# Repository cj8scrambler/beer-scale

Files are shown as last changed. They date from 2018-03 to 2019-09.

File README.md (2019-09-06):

# Keg Scale
This is a project to monitor the amount of beer left in my keggerator by weighing them and providing a web interface to view the data.

### Architecture
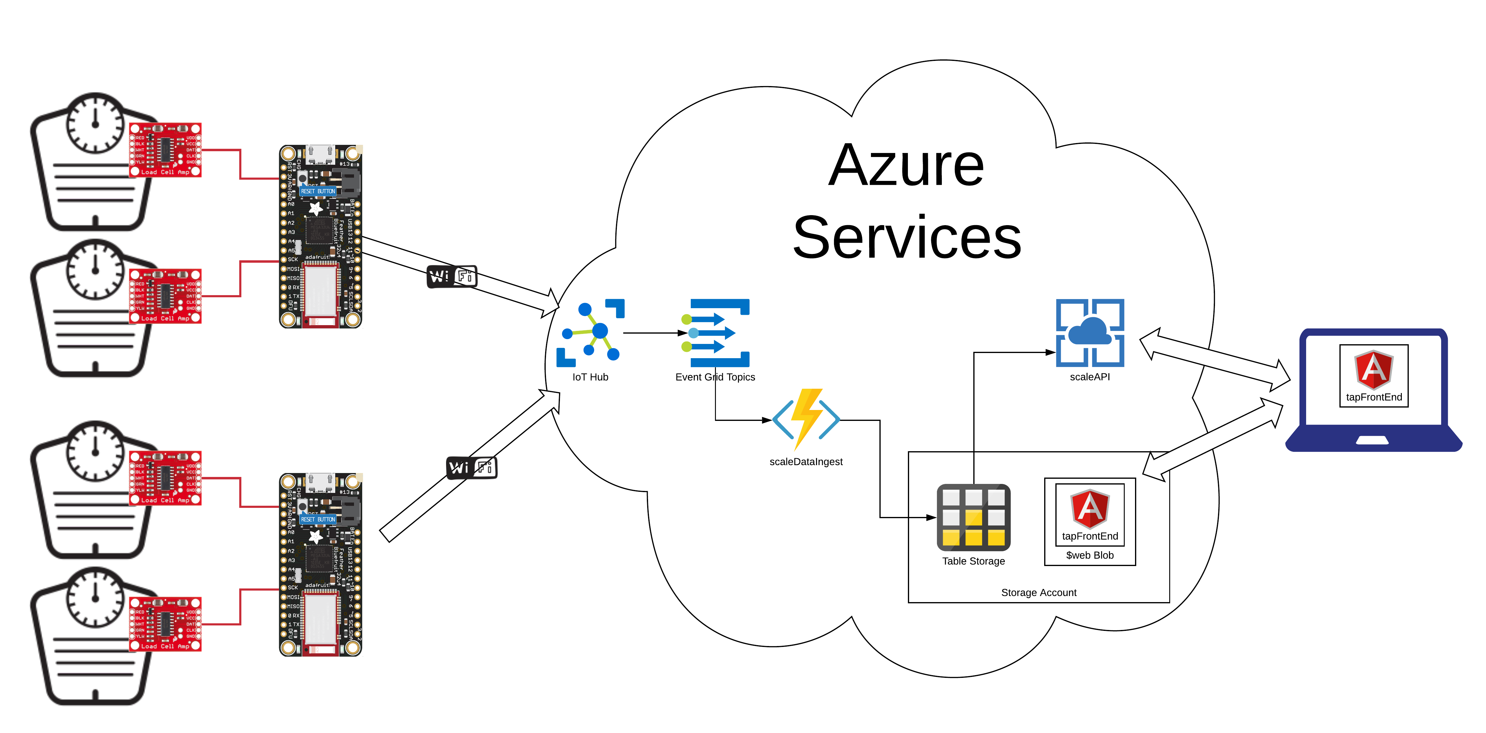
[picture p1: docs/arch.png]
arch


##### Scales
Custom scales were created which fit in the keggerator.  In my case they are 9" x 9.75".  The scales are made from a 1/2" thick sheet of HDPP plastic [cutting boards](https://www.amazon.com/gp/product/B01LXE0MBM/ref=oh_aui_search_detailpage?ie=UTF8&psc=1).  [50kg load cells](https://www.amazon.com/gp/product/B071ZYYJHJ/ref=oh_aui_search_detailpage?ie=UTF8&psc=1) are placed in each corner.  The load cells are held in place using a custom [3D printed clip](hw/).

##### Scale Wiring
Sparkfun has a great [tutorial](https://learn.sparkfun.com/tutorials/load-cell-amplifier-hx711-breakout-hookup-guide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) on wiring and using load cells.  I used their [Load Cell Combinator](https://www.sparkfun.com/products/13878) and [Qwiic Scale - NAU7802 board](https://www.sparkfun.com/products/15242) to wire up the scales for prototyping.  Eventually I will use a custom PCB for the scales' interface.

##### Reading Data
Currently data is read and sent to the cloud by a $10 [ESP8266 Huzzah](https://www.adafruit.com/product/2471).

##### Backend
I've included a [shell script](azure/provision.sh) which can be used to automaticlly provision all of the backend services needed on Azure from a Mac or Linux (possibly Windows too if there's a bash shell available).

##### Sending Data
The [Azure IOT SDK](https://github.com/Azure/azure-iot-sdk-c) is used to send data directly from the Arduino to the Azure backend.  Data is stored in Azure Table service which is the cheapest solution I could find.

##### Accessing Data
An Angular frontend app presents the data to the user.

### Organization
Each Arduino can handle up to 8 scales (using 4 NAU7802 devices).  Multiple Arduinos can be used and presented under a single web interface.

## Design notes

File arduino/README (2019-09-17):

Arduino IDE Setup:

  File->Preferences->Additional Boards Manager URLs: 
  *  https://arduino.esp8266.com/stable/package_esp8266com_index.json
  *  Be sure to install v2.4.2 to avoid issue: https://github.com/esp8266/Arduino/issues/5787

  Install Libraries:
  *  AzureIoTHub
  *  AzureIoTUtility
  *  AzureIoTProtocol_MQTT
  *  ArduinoJson
  *  SparkFun Qwiic Scale NAU7802 Arduino Library
     Be sure to install v1.0.3 or later to get my non-blocking calibration changes

-------------------------------------------------------------

Or build / upload directly from the command line:

  Install arduino-cli:
  *  curl -fsSL https://raw.githubusercontent.com/arduino/arduino-cli/master/install.sh | BINDIR=~/bin sh

  Configure arduino-cli:
  *  arduino-cli config init
  *  edit ~/.arduino15/arduino-cli.yaml and replace the board_manager line with:
     board_manager:
       additional_urls:
         - http://arduino.esp8266.com/stable/package_esp8266com_index.json
  *  arduino-cli core update-index

  Install dependencies:
  *  arduino-cli core install esp8266:esp8266@2.4.2
  *  arduino-cli lib install AzureIoTHub
  *  arduino-cli lib install AzureIoTUtility
  *  arduino-cli lib install AzureIoTProtocol_MQTT
  *  arduino-cli lib install ArduinoJson
  *  arduino-cli lib install "SparkFun Qwiic Scale NAU7802 Arduino Library"

  Build
  *  make 

  Upload 
  *  make upload        # set serial port path in Makefile

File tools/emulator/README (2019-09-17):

Python script to generate some dummy data emulating a scale
device.  If you don't have the arduino hardware working,
this can be used to fill the pipeline with some data.

Be sure to update the CONNECTION_STRING constant inside the
scale.py script!  The value to put here is printed by the
provision.sh script as "Node# Connection String" (where #
is any one of the multiple nodes available)

Script depends on the Azure IOT client python SDK which is
hard to install.  This is how I got it working:

# May need to add swap disk if < 2GB RAM avaialble
  sudo dd if=/dev/zero of=swapfile bs=1M count=3000
  sudo mkswap swapfile
  sudo swapon swapfile

# Pull Azure Python IOT SDK
git clone --recursive https://github.com/Azure/azure-iot-sdk-python.git
cd azure-iot-sdk-python/build_all/linux

# Build/Install for python 2
./setup.sh
./build.sh
cp ../../c/cmake/iotsdk_linux/python/src/iothub_client.so release_device_client/iothub_client/
cd release_device_client/
sudo python setup.py install
sudo cp -r iothub_client/ /usr/local/lib/python2.7/dist-packages/

# Clean up
cd -
git clean -xdf

# Build/Install for python 3
./setup.sh --python-version 3.6
./build.sh --build-python 3.6
cp ../../c/cmake/iotsdk_linux/python/src/iothub_client.so release_device_client/iothub_client/
cd release_device_client/
sudo python3 setup.py install
sudo cp -r iothub_client/ /usr/local/lib/python3.6/dist-packages/

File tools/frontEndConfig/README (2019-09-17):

Command line utility to configure the configuration database which the
frontend web app uses.

Be sure to update these 2 variables in the config.py script before running:
  STORAGE_ACCT_NAME
  STORAGE_ACCT_KEY

To run in a virutal env:
  python3 -m venv venv
  source venv/bin/activate
  pip install -r requirements.txt
  python ./config.py

Note: A scale must report some data in order to create an entry in the
configuration database.  So the arduino based hardware setup, or the
emulator script needs to be used to populate the configuration database
before this script is run to edit the details.

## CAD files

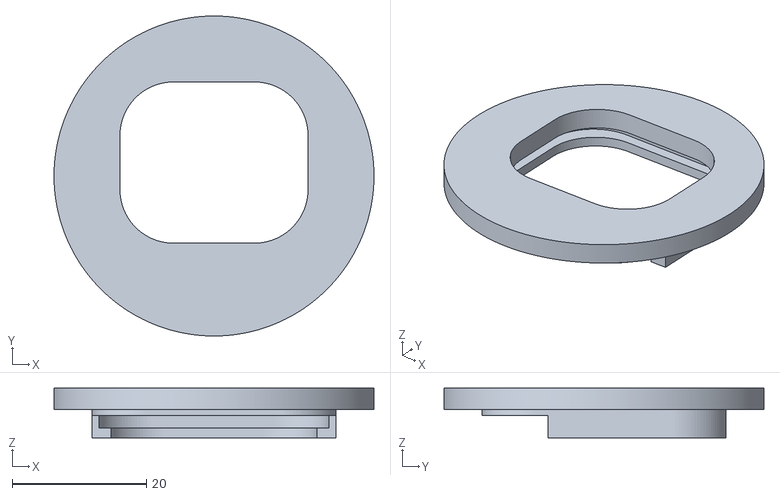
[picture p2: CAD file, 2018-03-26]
hw/sensor_clip/clip.stl
47.6 x 47.6 x 7.42

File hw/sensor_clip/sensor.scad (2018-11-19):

// Fine detail
$fa = 0.5;
$fs = 0.5;

// Coarse detail
//$fa = 1.0;
//$fs = 1.5;

sensor_width = 34;
sensor_thick = 2.5;
sensor_corner_radius = 8;

edge_width = 3;      // width of 3 sides
top_width = 7;     // width of 4 side

tongue_width = 8; // width of tongue running to U shape (also bottom of U)

u_total_width =  22; // width of outsides of U shape
u_height = 16;       // height of U shape
u_y_offset = 3;      // vertical offset of U shape
u_bar_width = 4;     // width of vertical bars of U shape
u_radius = 4;        // radius @ top of vertical bars of U shape


fudge = 1; // used to make subtractive area a little thicker
hole_x = sensor_width - 2 * edge_width;
hole_y = sensor_width - edge_width - top_width;

module rounded_square(x, y, z, corner_radius) {
  union()
  {
    radius_offset_x = x / 2 - corner_radius;
    radius_offset_y = y / 2 - corner_radius;

    // 4 corners from circles
    translate([radius_offset_x,radius_offset_y,0])           cylinder(r=corner_radius, h=z);
    translate([-1 * radius_offset_x,radius_offset_y,0])      cylinder(r=corner_radius, h=z);
    translate([radius_offset_x,-1 * radius_offset_y,0])      cylinder(r=corner_radius, h=z);
    translate([-1 * radius_offset_x,-1 *radius_offset_y,0])  cylinder(r=corner_radius, h=z);

    // fill in the middle with bars
    translate([0,0,(z/2)])  cube([x,2*radius_offset_y,z],center=true);
    translate([0,0,(z/2)])  cube([2*radius_offset_x, y,z],center=true);
  }
}

// Sensor
// Remove the * to uncomment and show the sensor inside the clip:
*color([0.7,0.7,0.7]) union()
{
    union()
    {
        //edge ring
        difference()
        {
            rounded_square(sensor_width, sensor_width, sensor_thick, sensor_corner_radius);
            translate([0,(top_width-edge_width)/2,fudge/-2]) rounded_square(hole_x, hole_y, sensor_thick+fudge , sensor_corner_radius);
        }

        // toungue
        offset_from_bottom = u_height + u_y_offset + edge_width;
        translate([0,-1*(sensor_width - offset_from_bottom)/2, sensor_thick/2]) cube([tongue_width, sensor_width - offset_from_bottom, sensor_thick], center=true);

        // U Shape
        difference()
        {
            union()
            {
                translate([0,(edge_width)]) rounded_square(u_total_width, u_height, sensor_thick , sensor_corner_radius/2);
                translate([9,-edge_width,0]) cylinder(r=2.0, h=sensor_thick);
                translate([-9,-edge_width,0]) cylinder(r=2.0, h=sensor_thick);
            }
            // just harcode these holes
            translate([5.7,-edge_width,-0.5]) rounded_square(3, 16, sensor_thick+1 , 1);
            translate([-5.7,-(edge_width),-0.5]) rounded_square(3, 16, sensor_thick+1 , 1);
        }
    }

    difference()
    {
        hull()
        {

            translate([-9,-edge_width,0]) difference()
            {
                translate([0,0,-sensor_thick]) rounded_square(6, 7, sensor_thick , 2);
                translate([3.7,0,sensor_thick/-2]) cube([3, 7, sensor_thick+1] , center=true);
            }
            translate([8,-edge_width,0]) difference()
            {
                translate([0,0,-sensor_thick]) rounded_square(6, 7, sensor_thick , 2);
                translate([-2.5,0,sensor_thick/-2]) cube([3, 7, sensor_thick+1] , center=true);
            }
            translate([0,-edge_width,-2*sensor_thick]) rounded_square(7, 7, sensor_thick , 2);
        }
        translate([0,-edge_width,-0.5*sensor_thick]) cube([9,9,sensor_thick], center=true);
    }
    difference()
    {
        translate([0,-edge_width,-1.5*sensor_thick]) sphere(r=2, h=3);
        translate([0,-edge_width,-0.5*sensor_thick]) cube([9,9,sensor_thick], center=true);
    }
}

clip_thickness = 2.0; // wall thickness
clip_rise = 1.5; // thickness above clip
buffer = 0.25;  // space between sensor and clip

nub_height = 1.0; // thickness of nub that holds clip in
len_percentage = 0.35; // perctage of sensor length not covered by clip
width_percentage = 0.85; // width of clip top

//base_radius=25.4;  //  2" diameter circle)
base_radius=23.8125;  // 1 7/8" diameter circle)
base_depth=3.175;   // 1/8"

union ()
{
    clip_outside = sensor_width+clip_thickness+buffer;
    clip_inside = sensor_width+buffer;

    // round base
    translate([0,0,sensor_thick]) difference ()
    {
        cylinder(r=base_radius, h=base_depth);
        translate([0,(top_width-edge_width)/2,fudge/-2]) rounded_square(hole_x, hole_y, base_depth+fudge , sensor_corner_radius);
    }

    difference() {
        union()
        {
            // clip perimiter
            difference()
            {
                translate([0,0,-clip_rise]) rounded_square(clip_outside, clip_outside, sensor_thick+clip_rise, sensor_corner_radius);
                translate([0,0,-clip_rise-fudge/2]) rounded_square(clip_inside, clip_inside, sensor_thick+clip_rise+fudge, sensor_corner_radius);
            }

            // top ridge
            difference()
            {
                translate([0,0,-clip_rise-buffer]) rounded_square(clip_outside, clip_outside, clip_rise, sensor_corner_radius);
                translate([0,0,-clip_rise-buffer-fudge/2]) rounded_square(width_percentage*clip_outside, width_percentage*clip_outside, clip_rise+fudge, sensor_corner_radius);
            }
        }
        // cutaway
        color([0.1,0.1,0.7]) translate([0,-0.5*(clip_outside*(1-len_percentage)+fudge),-nub_height]) cube([clip_outside+fudge,clip_outside*len_percentage+fudge,sensor_thick+clip_rise+fudge],center=true);
    }
}

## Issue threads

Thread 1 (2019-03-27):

Arduino -> Raspberry Pi

johnluddy, 2019-03-27:
Great project. Not an issue, rather a request to gain insight on a couple design points.

Access to Scales/data outside unit -- From your description & diagram of Pi reading the BLE data from any available Arduinos, I am assuming the Pi was powered & mounted outside the kegerator and Arduino(s) mounted inside.  Correct?  If so, did you have any issues accessing the data via BLE reader given the insulation of the fridge?  Designing mine with different units in mind and picturing fridge units with different thickness being an issue but have not tested yet.

Arduino mount -- Did you mount the Arduino to one of the scales or inside wall of fridge unit?

Batteries used -- It reads like you used battery power inside the unit.  Can you share what worked best for you?

Thanks for sharing your efforts.  Such a great resource!

cj8scrambler, 2019-03-29:
To be honest, this is a slow moving project that hasn't actually made it into the keggerators yet.  I am still working on it, but progress is slow.

I have placed the Arduino inside the keggerator to test signal strength.  I'm able to reliably receive the BLE weight data on my phone from at least 10 ft. away.  My plan is to place the raspberry pi just outside of the kegerator in a nearby drawer with AC power.

I haven't worked out mounting the arduino safely inside the keg.  It will probably end up velcro'ed to a wall with some type of connector to connect 2 scales.  Mounting the arduino on the scale will probably lead to it being crushed by a keg.

I have a Adafruit 350mAh battery (https://www.adafruit.com/product/2750), but I've done all the development using AC power so far.

I know the project isn't really usable by others as it is, it's more of a place to hold my ideas.  This is also my first time working in AWS, so all the backend code is embarrassing.  I'd love to see anyone build on it.

johnluddy, 2019-03-29:
Nor problem at all and thanks!  The update on the BLE data tests you did was what I was looking for and thanks for the tip on the battery.  Great to hear that worked outside the frig.  Just getting my prototype materials together and designing high level.  I may reach out for more questions and will let you know if I make progress.

I plan to use a similar design but plan include the Arduino in the scale housing.  Looking at options for that and may just start with a standard Bluetooth bath scale and add-on.

Sent from Outlook<http://aka.ms/weboutlook>

________________________________
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

cj8scrambler, 2019-03-29:
If space in the keggerator is not an issue then an off the shelf BLE scale would be simpler.  However be aware that many scales use custom interfaces, not the standard GATT 'Weight Scale' feature.  It wouldn't be impossible to figure out a custom interface, just another challenge.

BTW, I find the Nordic nRF Connect smartphone app indispensable for debugging BLE.

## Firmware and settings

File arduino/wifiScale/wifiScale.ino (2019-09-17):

/*
   Arduino based scale application using multiple NAU7802 ADCs
   connected with an I2C Mux.  Data is sent via wifi to an Azure
   backend.  Full details at:
     https://github.com/cj8scrambler/beer-scale

   Based on and including code from:

    Microsoft IOT arduino demo
    https://github.com/Azure/azure-iot-arduino

    Luis Llamas median filter
    https://github.com/luisllamasbinaburo/Arduino-MedianFilter

    NAU7802 Arduino Library
    https://github.com/Sawaiz/nau7802

*/
#include <ArduinoJson.h>
#include <Wire.h>

#include "common.h"
#include "scale.h"
#include "iothub.h"
#include "network.h"

//#define DEBUG                          1      // Enable verbose serial logging

NAU7802 adc[NUM_ADC];
Scale *scale[NUM_SCALES];                   // 2 scales per ADC
IotHub iothub;
Network network;

void setup() {
  int weight_change = false;
  int adc_offset, chan;
  uint16_t mv;
  char buffer[MESSAGE_MAX_LEN];
  uint32_t start = millis();
  bool run_scale_cal = false;

  // Start serial and initialize stdout
  Serial.begin(115200);
  Serial.setDebugOutput(false);
  Serial.println("");
  pinMode(LED_BUILTIN, OUTPUT);
  digitalWrite(LED_BUILTIN, HIGH); /* turn off LED */

  pinMode(CONFIG_SW_GPIO, INPUT_PULLUP);
  pinMode(AVDD_EN_GPIO, OUTPUT);
  digitalWrite(AVDD_EN_GPIO, HIGH);

  Wire.begin(I2C_SDA_PIN, I2C_SCL_PIN);

#ifdef DEBUG
  Serial.printf("%ld - Begin readings\r\n", start);
#endif

  // Read battery voltage
  // 10-bit ADC with 1:10 voltage divider scaled up to mv: /1024 * 10 * 1000
  mv = (uint16_t)((analogRead(A0) * 9.7656) + 0.5);

  run_scale_cal = initConfig();

  if (!digitalRead(CONFIG_SW_GPIO)) {
    Serial.println("Force reconfig due to config switch");
    run_scale_cal |= reconfig();
  }

  /* we're done checking for config mode; disable the pullup to save power */
  pinMode(CONFIG_SW_GPIO, INPUT);

  /* If scale calibration is needed, do that then sleep to reset setup sequence */
  if (run_scale_cal)
  {
    for(int adc_offset = 0; adc_offset < NUM_ADC; adc_offset++)
    {
      setmux(adc_offset);
      for(int chan = 0; chan < NUM_CHAN_PER_ADC; chan++)
      {
        int scalenum = adc_offset * NUM_CHAN_PER_ADC + chan;
        if (g_config->scaledata[scalenum].slope == 0.0)
        {
          scale[scalenum] = new Scale(&(adc[adc_offset]), chan, scalenum);
          scale[scalenum]->begin(&g_config->scaledata[scalenum]);
          scale[scalenum]->calibrate(g_config->refweight);
        }
      }
    }

    /* save new settings to EEPROM */
    saveSettings();

    setmux(-1);

    Serial.println("Scale calibrations complete.  Reseting....");
    /* This will never return; actually goes back to begining of setup() */
    ESP.deepSleep(1000);
  }

  /* Provision scale devices for real
   * Loop order (chan then ADC) is important to minimize recalibrations delays
   */
  for(int chan = 0; chan < NUM_CHAN_PER_ADC; chan++)
  {
    /* Provision, initialize and begin calibration on each */
    for(int adc_offset = 0; adc_offset < NUM_ADC; adc_offset++)
    {
      int scalenum = adc_offset * NUM_CHAN_PER_ADC + chan;
      setmux(adc_offset);
      scale[scalenum] = new Scale(&(adc[adc_offset]), chan, scalenum);
      scale[scalenum]->begin(&g_config->scaledata[scalenum]);
    }

    /* Check network while ADC calibration is happening */
    if (!network.isConnected())
    {
      if (!network.connectWifi(g_config->ssid, g_config->pass) ||
          !iothub.init(g_config->connection, g_config->deviceid))
      {
        /* If we can't connect then go to sleep
         * and hope things get better later */
        goto done;
      }
    }

    /* Get the datapoint from each ADC when it's ready */
    for(int adc_offset = 0; adc_offset < NUM_ADC; adc_offset++)
    {
      int scalenum = adc_offset * NUM_CHAN_PER_ADC + chan;
      if (scale[scalenum]->enabled())
      {
        setmux(adc_offset);
        if (scale[scalenum]->waitForReady(1000))
        {
          scale[scalenum]->datapoint();

          DynamicJsonDocument root(MESSAGE_MAX_LEN);
          root["timestamp"] = network.getTime();
          root["deviceid"] = g_config->deviceid;
          root["scale"] = scale[scalenum]->scaleNum();
          root["weight"] = scale[scalenum]->weight();
          root["voltage"] = mv;
#ifdef DEBUG
          Serial.println("Generated message:");
          serializeJsonPretty(root, Serial);
          Serial.println();
#endif
          serializeJson(root, buffer, MESSAGE_MAX_LEN);
          iothub.sendMessage(buffer);

          Serial.printf("%ld - %ld: reported scale-%d: %.1f Kg %s\r\n",
                        millis(),
                        (time_t) root["timestamp"], scalenum,
                        ((float)root["weight"]) / 1000.0,
                        scale[scalenum]->recentWeightChange()?
                        "(change)":"");
          weight_change |= scale[scalenum]->recentWeightChange();
        }
        else
        {
          Serial.printf("%ld Error waiting for scale-%d to become ready\r\n", millis(), scalenum);
        }
      }
    }
  }

done:
  setmux(-1);

  if (network.isConnected())
  {
    iothub.doWork();
    delay(5);
  }

#ifndef SIMULATE
  for (adc_offset = 0; adc_offset < NUM_ADC; adc_offset++)
  {
    if (adc[adc_offset].isConnected())
      adc[adc_offset].powerDown();
  }
#endif
  digitalWrite(AVDD_EN_GPIO, LOW);

  /* saves config/state info to EEPROM */
  saveSettings();

  Serial.printf("%ld - Waiting on iothub to finish\r\n", millis());
  while (network.isConnected() && iothub.workPending()) {
    iothub.doWork();
    delay(10);
  }
  Serial.println();

  /* deepsleep will cause board to reset to setup() on wakeup */
  int sleeptime = weight_change ? SHORT_SLEEP_TIME_S : LONG_SLEEP_TIME_S;
  Serial.printf("Uptime %0.2fS; Sleeping for %d seconds\r\n", (millis() - start) / 1000.0, sleeptime);

  digitalWrite(LED_BUILTIN, HIGH);
  ESP.deepSleep(sleeptime * 1000000);
}

void loop() {
}

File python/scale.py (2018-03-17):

#!/usr/bin/python3
import sys
import time
import json
import statistics
import datetime
import os.path
import RPi.GPIO as GPIO
from hx711 import HX711  # https://github.com/tatobari/hx711py
from AWSIoTPythonSDK.MQTTLib import AWSIoTMQTTClient

from scaleconfig import scaleConfigs
from scaleconfig import THING
from scaleconfig import GROUP
from scaleconfig import ENDPOINT

LOGFILE = "/var/log/scale.log"

# Paramaters for MQTT reporting rate control
# Samples are taken and stored locally.  A median of those samples
# is taken and reported via MQTT.  If the range of sample data has
# a lot of variance (weight change detected), then the mqtt reporting
# rate moves to the higher rate.  If the MQTT data reported has low
# variance (weight has stabalized for some time), then the mqtt reporting
# rate moves to the lower rate.
SAMPLE_PERIOD = 5           # seconds between reading scale data
MAX_SAMPLES_PER_MQTT = 180  # Max samples between MQTT updates (happens with stable weight)
MEDIAN_FILTER_SIZE = 5
MQTT_ALLOWED_VARIANCE = 5   # Variance (in grams) which triggers a new MQTT update

def cleanAndExit():
    GPIO.cleanup()
    myMQTTClient.unsubscribe("device/+/tare")
    myMQTTClient.disconnect()
    print ("%s: Bye!" % datetime.datetime.now())
    sys.exit()

def tareScale(scaleConfig):
    scaleConfig['tare_offset'] = hx.tare()
    print ("%s: Tare Value: %.2f" % (datetime.datetime.now(), scaleConfig['tare_offset']))

def getScaleConfig(name):
    global scaleConfigs
    for config in scaleConfigs:
        if (config['name'] == name):
            return config

def handleIncoming(client, userdata, message):
    path = message.topic.split("/")
    if (len(path) == 3):
        if (path[2] == "tare"):
            config = getScaleConfig(path[2])
            if config is not None:
                tareScale(config)
            else:
                print("Invalid Scale: %s" % path[2])
        else:
            print("Received unkown message topic: ")
            print(message.topic)
    else:
        print("Received invalid topic name: ")
        print(message.topic)
    

# Neet to allocate these dynamicaly based on number of scales
data = [[], []]
last_mqtt_report = [0,0];
updates = 0
scaleDevices = []

certdir = "aws_certs"
if (len(sys.argv) > 1):
    certdir = sys.argv[1];

if ((not os.path.isfile(certdir + "/VeriSign-Class 3-Public-Primary-Certification-Authority-G5.pem")) or
    (not os.path.isfile(certdir + "/affd2b97c0-private.pem.key")) or
    (not os.path.isfile(certdir + "/affd2b97c0-certificate.pem.crt")) ):
    print("Error: Could not find aws certificates in: " + certdir);
    print("Usage: " + sys.argv[0] + " [aws certs dir]");
    sys.exit(-1)

sys.stdout = sys.stderr = open(LOGFILE, 'a')

# Initialize Scales
for config in scaleConfigs:
    print("%s: Initializing %s (%d,%d) [%d/%d]" %
          (datetime.datetime.now(), config['name'],
           config['clk_gpio'], config['data_gpio'],
           config['ref_unit'], config['tare_offset']))
    hx = HX711(config['data_gpio'], config['clk_gpio'])
    hx.set_reading_format("LSB", "MSB")
    hx.set_reference_unit(config['ref_unit'])
    hx.reset()
    hx.set_tare(config['tare_offset'])
    scaleDevices.append(hx)

# Initialize MQTT session
myMQTTClient = AWSIoTMQTTClient(THING)
myMQTTClient.configureEndpoint(ENDPOINT, 8883)
myMQTTClient.configureCredentials(certdir + "/VeriSign-Class 3-Public-Primary-Certification-Authority-G5.pem",
                                  certdir + "/affd2b97c0-private.pem.key",
                                  certdir + "/affd2b97c0-certificate.pem.crt")
myMQTTClient.configureOfflinePublishQueueing(-1)  # Infinite offline Publish queueing
myMQTTClient.configureDrainingFrequency(2)  # Draining: 2 Hz
myMQTTClient.configureConnectDisconnectTimeout(10)  # 10 sec
myMQTTClient.configureMQTTOperationTimeout(5)  # 5 sec
print ("%s: Connect to MQTT endpiont: %s  thing: %s" %
       (datetime.datetime.now(), ENDPOINT, THING))
myMQTTClient.connect()
myMQTTClient.subscribe("device/+/tare", 1, handleIncoming)

while True:
    try:
        weight_change = False;
        updates += 1
        # Read each scale
        i = 0
        while i < len(scaleDevices):
            val = scaleDevices[i].get_weight(5)[0]
            data[i].append(val)

            while len(data[i]) > MEDIAN_FILTER_SIZE:
                data[i].pop(0)

            print ("%s: %s:  %.1f kg    [Val: %.2f  Size: %d/%d   update: %d/%.1f]" %
                    (datetime.datetime.now(), scaleConfigs[i]['name'], statistics.median(data[i]) / 1000.0,
                     val, len(data[i]), MEDIAN_FILTER_SIZE, updates % MAX_SAMPLES_PER_MQTT, MAX_SAMPLES_PER_MQTT))
            scaleDevices[i].power_down()
            scaleDevices[i].power_up()

            if (abs(statistics.median(data[i]) - last_mqtt_report[i]) > MQTT_ALLOWED_VARIANCE):
                print ("  Detected weight change on %s: delta: %.1f" % (scaleConfigs[i]['name'], statistics.median(data[i]) - last_mqtt_report[i]));
                weight_change = True;
            i += 1

        if ((weight_change == True) or ((updates % MAX_SAMPLES_PER_MQTT) == 0)):
            # Send a single MQTT message with all of the scale readings
            update = {}
            update['state'] = {}
            update['state']['reported'] = {}
            update['state']['reported']['taps'] = []
            j = 0
            while j < len(scaleDevices):
                weight = round(statistics.median(data[j]), 1)
                datapoint = dict()
                datapoint['tap'] = scaleConfigs[j]['name']
                datapoint['thing'] = THING
                datapoint['group'] = GROUP
                datapoint['timestamp'] = int(time.time())
                datapoint['weight'] = weight

                update['state']['reported']['taps'].append(datapoint)

                last_mqtt_report[j] = weight;

                j += 1
            messageJson = json.dumps(update)
            myMQTTClient.publish("$aws/things/" + THING + "/shadow/update", messageJson, 1)
            print ("%s: MQTT send to %s: %s" % (datetime.datetime.now(),
                   "$aws/things/" + THING + "/shadow/update", messageJson))
            updates = 0;


        sys.stdout.flush()
        sys.stderr.flush()
        os.fsync(sys.stdout.fileno())
        os.fsync(sys.stderr.fileno())
        time.sleep(SAMPLE_PERIOD)
    except (KeyboardInterrupt, SystemExit):
        cleanAndExit()

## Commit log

2018-03-10 iot2simpledb: Node.js script to save incoming IOT data
    AWS lambda function which takes an IOT trigger and sends the data
    to SimpleDB and updates the IOT shadow device.
2018-03-10 get_devices: Node.js script to implement a REST API
    AWS lamda script which uses an API trigger to return current
    state information.
2018-03-11 python: add GROUP, fix fast sample logic
    Add GROUP back into broadcast values. Easier to just send it then
    to try to figure it out on the server side.
    Fix logic so fast sample rate happens if any scale sees a change.
    [scale.py]
2018-03-16 python: Update report rate algorithm
    Better filtering of false positives, more repsonsive to weight
    change and simpler logic.
2018-03-20 hw: add a rough model for the sensor
    The outside dimensions are accurate, the rest is a rough approximation
    of the load sensors I bought.
    [sensor.scad]
2018-03-26 hw: Idea for a clip to hold the sensor
    Small clip with a round base that can be counter-sunk into the platform
    using a forstner bit.
    [clip.stl, sensor.scad]
2018-03-26 html: Update static page to add graph with historical data
    Currently hardcoded for 1 tap
2018-04-12 scale: Add a calibration mode
    If scale name (--scale) and calibration weight (--weight) are specified,
    then the script will go into a calibration mode for that scale. Written,
    but not tested yet.
2018-04-24 scale: Switch to kernel driver for sampling hx711
    User space bit banging python driver is not stable. It worked OK
    on a Raspberry Pi 3, but once I switched to a Pi Zero, it was mostly
    garbage data. The bit banged clock line can't meet the tight timing
    requirement of the HX711. Switching to the kernel driver for this
    gives much more reliable data on lightweight systems like Pi Zero.
    [scale.py]
2018-10-06 Start on BLE weight reader
    Moving the HX711 reading to an Arduino so that it's more reliable.
    This is an attempt at creating a python script to read those weight
    readings from the Arduino by BLE.
2018-11-14 arduino: Create arduino BLE scale reader
    After multiple failures trying to reliably read HX711 data using
    a Raspberry Pi, I gave up and switched to an Arduino. The intermittant
    latency on the RPi was causing corruption on the HX711 readings.
    I've switched to using an Adafruit Feature 32u4 Bluefruit LE to
    interface with the HX711. It periodicly takes readings. When it
    detects a weight change, or if enough time has elapsed, then it
    broadcasts the reading using the WeightScale GATT profile in BLE.
    The RPi can connect via BLE now and reliable get the readings and
    pass them up to AWS.
2018-11-14 scale: Switch to using BLE scale
    Instead of trying to read the HX711 directly on RPi (which wasn't
    reliable), use an Arduino to read the data and send it here via
    BLE.
    scale.py runs as a daemon reading BLE data and sending results
    up to AWS IOT. scaleconfig.json contains the configuration for
    the BLE and AWS interfaces.
2018-11-14 scale: remove scale code that ran on RPi; rename blescale
    Previous functionality from 'scale.py' has been split between an
    Arudino (code in arduino/) and a ble scale receiver (code in
    raspberrypi)
2018-11-19 hw: shrink top of clip to prevent breaking
    First prints I made were SLA and the top ridge of the clips
    broke when I inserted the sensors. This probably won't have
    been an issue with PLA. Moved the cutaway a little further
    back for the 2nd try.
    [sensor.scad]
2019-03-05 Report all cached data in a single MQTT update
    AWS IOT overwrites the shadow update with the latest update. So
    each update must contain all sensor data. This is handled by
    caching values in scale.py and reporting all data on each MQTT
    write.
2019-03-29 arduino: Add dynamic naming and other cleanup
    Cleaned up the arduino code and added a README for dependencies.
    Added support for changing the arduino device name and individual
    scale names via 'Model Number String' parameters.
    Cleaned up calibration code and seperated calibration (one time
    event) from tare (common event). Either can now be triggered via
    BLE using custom command interface. Bit meanings are described
    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
2019-07-26 azure: Script to provision backend resources
    Create a bash script to provision backend services on Azure needed
    to support the scale data. Running this script will provision
    backend services which WILL INCUR COSTS. The defaults values are
    cheap/free options, but costs will scale with use.
    Re-running the script (with the same arguments) will validate the
    existing services already provisioned, it will NOT provision
    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
2019-07-26 azure: scale device emulator
    Python script to emulate scale hardware with dummy data.
2019-08-30 azure: tapsFrontEnd: Update favicon
    Switch the Angular favicon for a custom one
2019-08-30 arduino: arduino app for scale sensing
    Completely new arduino app which sends data directly to Azure.
    * Based on $10 Adafruit ESP8266 Huzzah board (not feather)
    * Reports directly to Azure iothub over wifi
    * Uses NAU7802 to perform scale A/D readings
    * Allows for I2C mux to handle multiple NAU7802 ICs
2019-09-06 doc: Update the documnetation for the big arch changes
    Completely changed the architecture. Update the diagram,
    README and remove old unused code for these changes:
    * Switched from $25 BLE feather to $10 WiFi ESP8266 Huzzah
    * Got rid of the Raspberry Pi
    * Switched from AWS to Azure
    * New Angular frontend app
2019-09-17 arduino: Switch ADC library and improve power consumption
    Various updates including:
    * remove the old BLE based kegscale code
    * switch to Adafruit NAU7802 libaray with updates to support
    non-blocking calibration
    * Runtime optimizations to reduce power consumption
    * Make calibration reference weight runtime configurable
    * Put some string sanity checks on EEPROM data
    * Avoid duplicate iothub connections
    [common.h, config.ino, iothub.cpp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]
